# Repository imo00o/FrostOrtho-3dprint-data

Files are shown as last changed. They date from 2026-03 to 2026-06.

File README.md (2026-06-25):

# FrostOrtho-3dprint-data
個人利用の範囲でしたら自由に使用・改変いただけます。  

## バージョン
- v1.2.0  
2026年6月22日以降に頒布しているケース。  
v1.2.0から基板や一部パーツが変更されたためv1.1.0以前と互換性なし。  

- v1.1.0  
2026年5月～6月中旬に頒布しているケース。  
v1.0.0から細かな改善をしたもの。  

- v1.0.0  
キーケット2026以前に頒布した際のケース。  
v1.1.0と互換性があるのでv1.1.0の使用をおすすめします。  

- V0  
試作段階のもの。  
電源スイッチが少し奥にあるため現行のケースとトップケースが少し異なるためv1.0.0以降と互換性がありません。  

## ケース作成
### v1.1.0 ～ v1.2.0
ケースを印刷/発注しただけでは使用できず、別途スポンジやマグネット等の取り付けが必要になります。

#### 必要なもの
| 部品名 | 説明 | 参考購入先 |
| -- | -- | -- |
| スポンジシート(3mm) | ボトムケースに敷くスポンジシート。ポロンスポンジがへたりにくくておすすめです。 | https://www.amazon.co.jp/dp/B00G468722?ref=ppx_yo2ov_dt_b_fed_asin_title&th=1 |
| スポンジシート(2mm) | トップケースに貼るスポンジシート。使いやすくてテープ状のものを使用していますが、2mmくらいの厚さであればなんでも。<br> 透明ケースの場合は100均等にある透明の両面テープが見た目綺麗でおすすめです。 | https://www.amazon.co.jp/dp/B0DDJDYVHX?ref_=ppx_hzsearch_conn_dt_b_fed_asin_title_5&th=1 |
| マグネット(直径2mm × 厚さ1mm) | トラックボールケースとトップケースを着脱可能にするための磁石 | https://www.amazon.co.jp/dp/B0FXB1RH63?ref_=ppx_hzsearch_conn_dt_b_fed_asin_title_1&th=1 |
| ベアリング(外形4mm 内径1.5mm 幅2mm) | トラックボールのベアリング | https://www.amazon.co.jp/dp/B0836S5376?ref_=ppx_hzsearch_conn_dt_b_fed_asin_title_6&th=1 |
| ネジ(M1.4 × 4~5mm) | ベアリングを固定するねじ | https://www.amazon.co.jp/dp/B076ZCH1NJ?ref_=ppx_hzsearch_conn_dt_b_fed_asin_title_1 |

#### 取り付け方
- ボトムケース  
  3mmのスポンジシートを7.5mmくらいの幅にカットします。  
  片面に両面テープを貼ってから切ると貼り付けるのが楽です。  
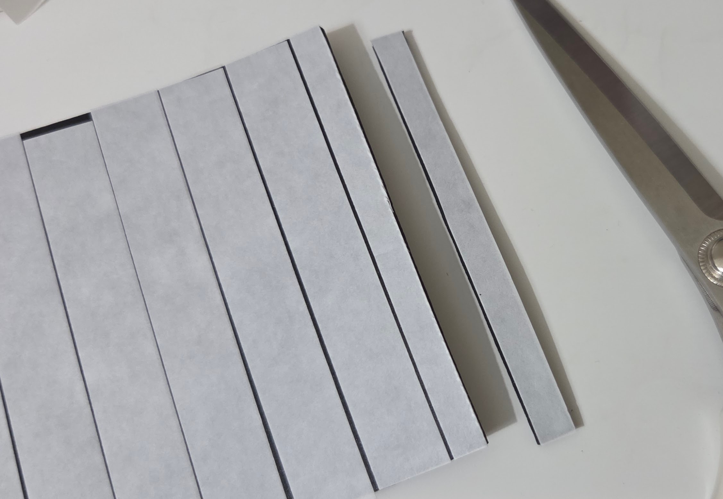
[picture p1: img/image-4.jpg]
   
凹みのある部分にスポンジシートを貼り付けます。  
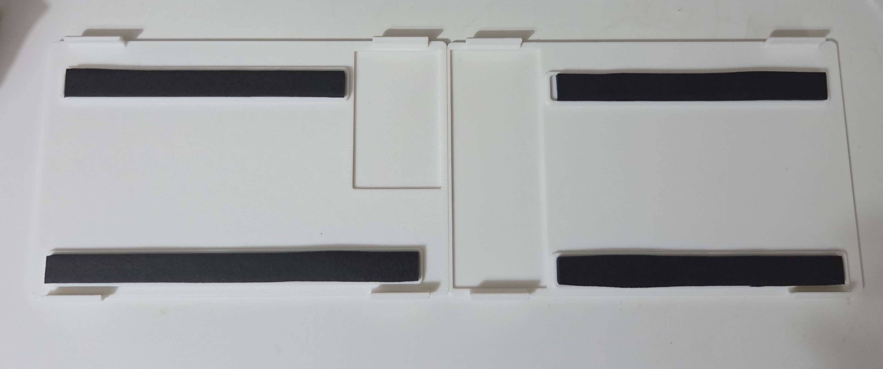
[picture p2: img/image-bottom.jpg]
   
- トップケース  
  2mmのスポンジシートを小さくカットして画像の位置に貼ってください。  
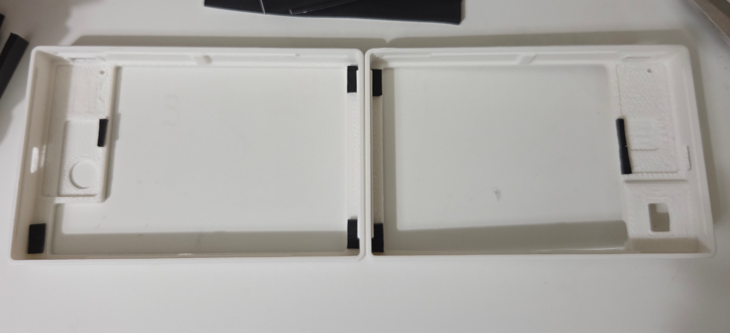
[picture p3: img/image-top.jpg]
     

## 発注方法（JLC3DP）
[JLC3DP](https://jlc3dp.com/jp?spm=Jlc3dp.Homepage.1001)での発注方法について簡単に紹介します。UIは更新される可能性があります。

1. アカウント登録を済ませて発注画面へ
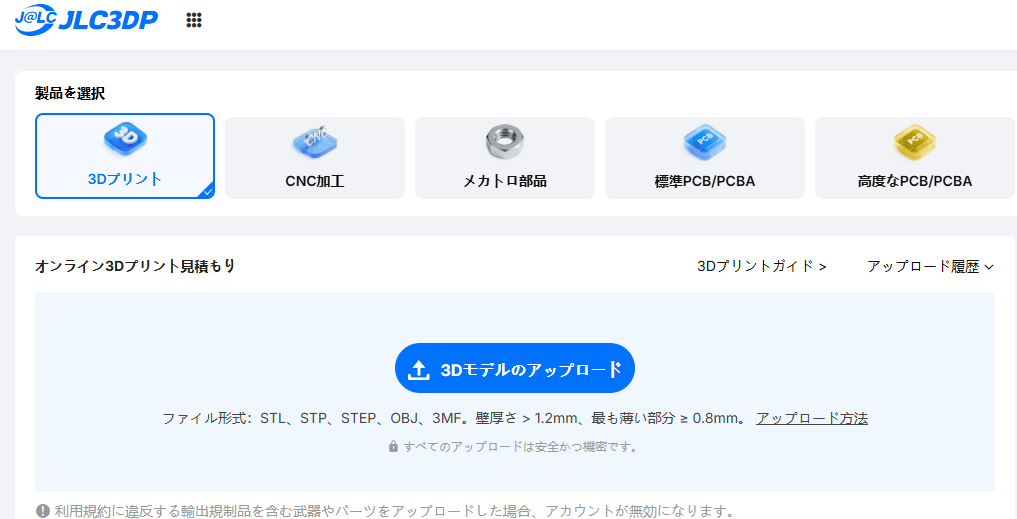
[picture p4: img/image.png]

2. STLファイルをアップロード
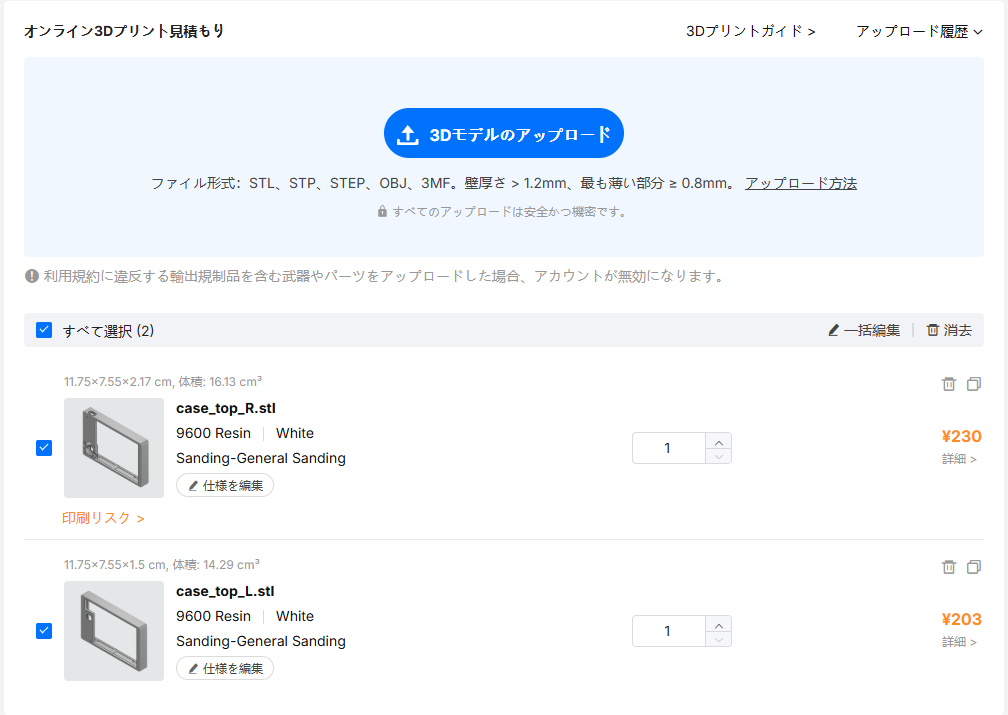
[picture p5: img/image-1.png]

3. 「使用を編集」をクリック
4. 好きな素材を選びます。以下ご参考ください。
   - クリア：SLA(Resin) > 8001レジン > 透明 > オイルスプレー仕上げ  
    表面を削った後にオイルスプレーするので品質にばらつきがあるものの、そのまま組み立てれて綺麗です。  
    ※ 素材の特性上歪んだ状態で届くことがあります。70~80度くらいのお湯で柔らかくして歪みを取ってください。
   - 半透明：SLA(Resin) > 8001レジン > 半透明 > 表面仕上げなし  
    結構バリがあるので自分でやすりがけ必須です。  
    やすりがけやコーティングが苦でなければ、こっちを綺麗に磨いてクリアケースにするのもいいかも。  
    ※ 素材の特性上歪んだ状態で届くことがあります。70~80度くらいのお湯で柔らかくして歪みを取ってください。
   - 黒：MJF(Nylon) > PA12S-HP Nylon > 黒色(染色)  
    PA12S-HPは質感がめちゃくちゃいいです。PA12-HPの方はざらつきが強いので注意。  
   - 例：
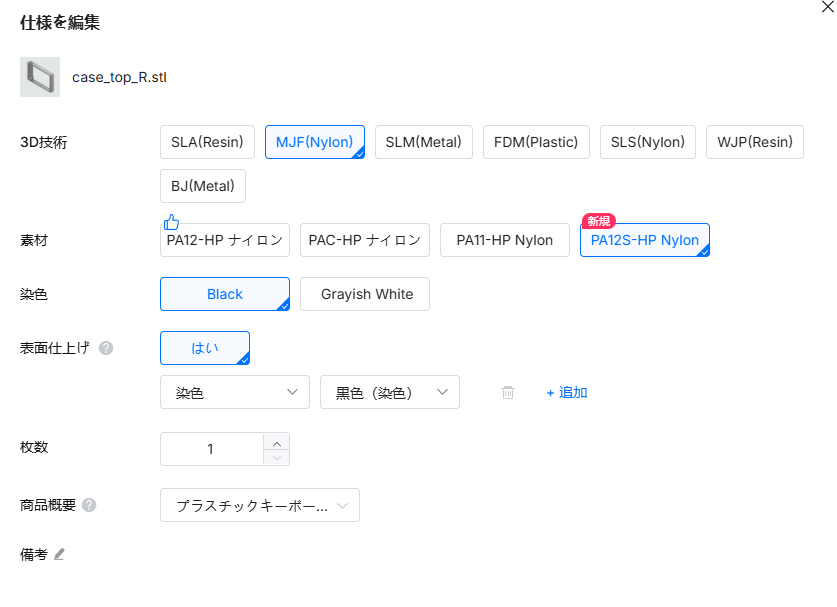
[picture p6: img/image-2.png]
    
5. 印刷リスクが表示された場合は、内容を確認してチェックをつけてください。
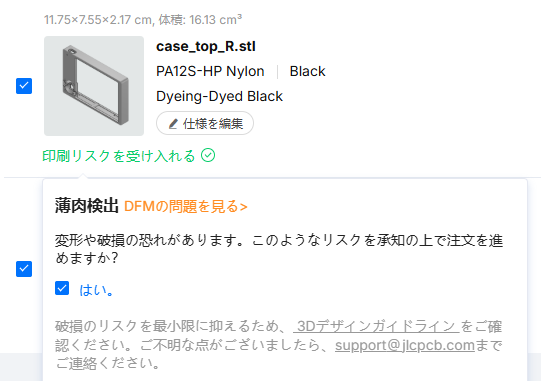
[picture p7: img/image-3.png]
   
6. すべてのパーツで素材を選択したら、「発注する」ボタンをクリック
7. 住所など必要な情報を入力して発注します。レビュー後の支払いになるので、この時点ではまだ支払いはしません。
8. レビュー結果がメールに届きます。  
9. トラボケースで指摘来ることが多いのですが、リスク許容するのでお願いします～て感じで返信してます。
10. すべてのレビューが完了し、Approvedとなったメールが届きます。
11. 発注履歴から支払いをすれば製作開始されます。
12. 製作途中で確認メールが届くことがあるので、届いたら都度対応します。
13. 「Your JLCPCB Order Is On Its Way To You」のメールが届いたらあとは届くのを待つだけです！

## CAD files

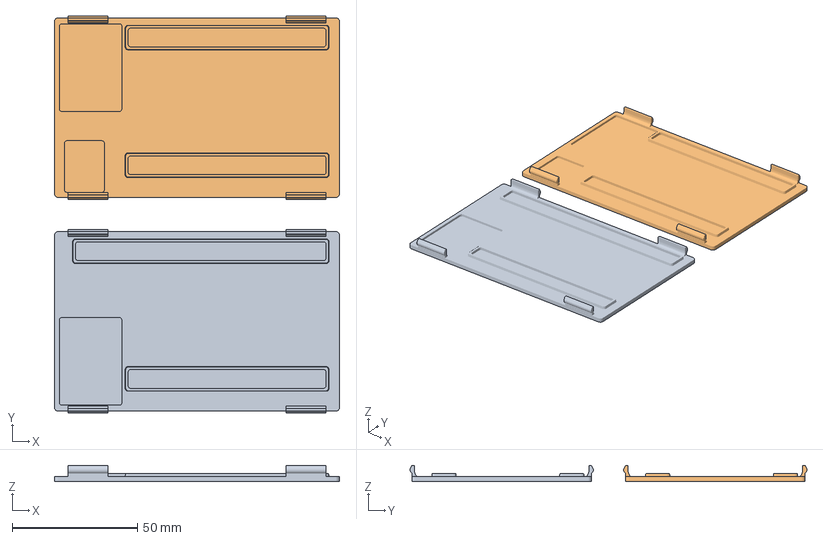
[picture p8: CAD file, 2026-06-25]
case/v1.2.0/3mf/case_bottom.3mf
113.8 x 158.5 x 6.47 mm
case_bottom_L.stl
case_bottom_R.stl

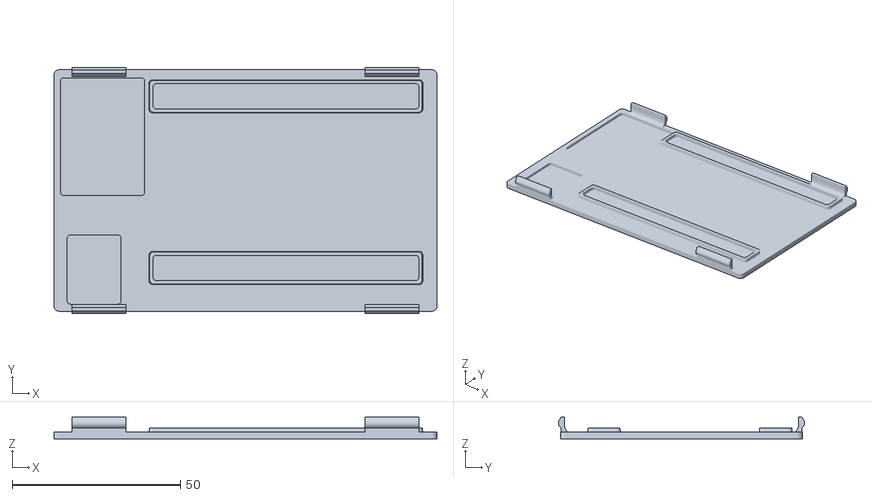
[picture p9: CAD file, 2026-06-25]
case/v1.2.0/stl/case_bottom_R.stl
113.8 x 73.2 x 6.47

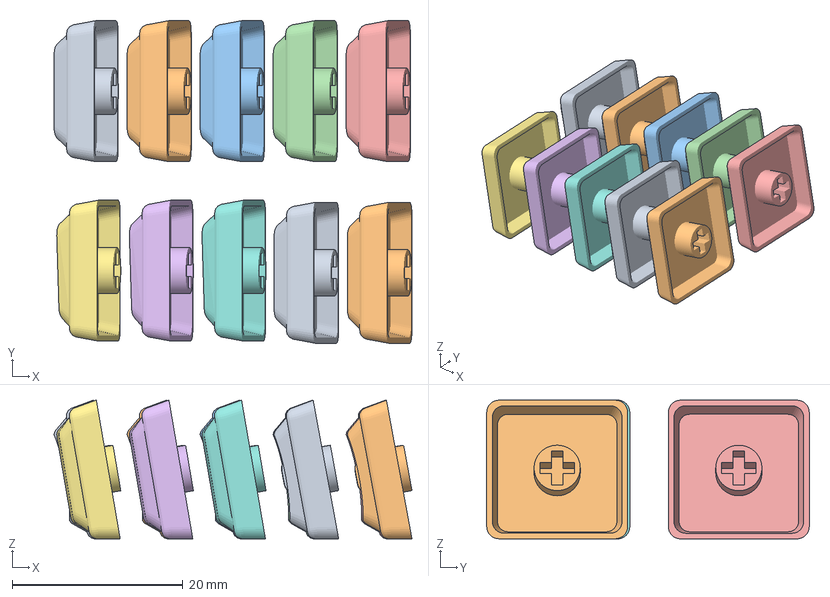
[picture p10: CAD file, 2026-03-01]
keycap/3mf/keycaps.3mf
41.9 x 37.8 x 16.3 mm
keycap-nomal.stl x 5
keycap-flat.stl x 3
keycap-point.stl x 2

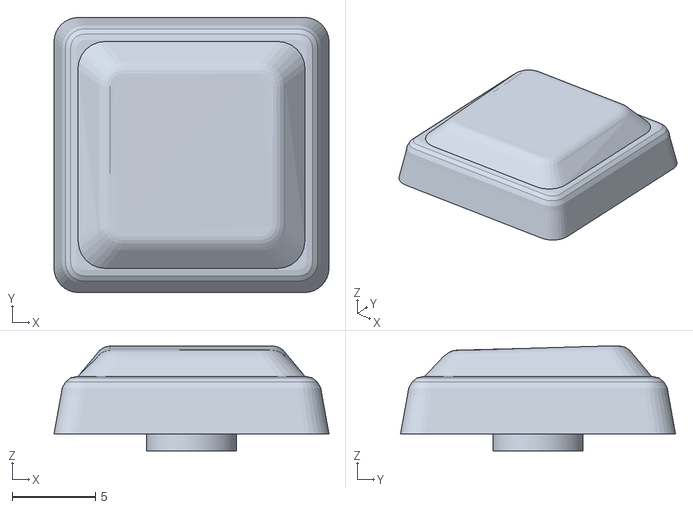
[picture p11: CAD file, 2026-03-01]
keycap/stl/keycap-flat.stl
16.5 x 16.5 x 6.30

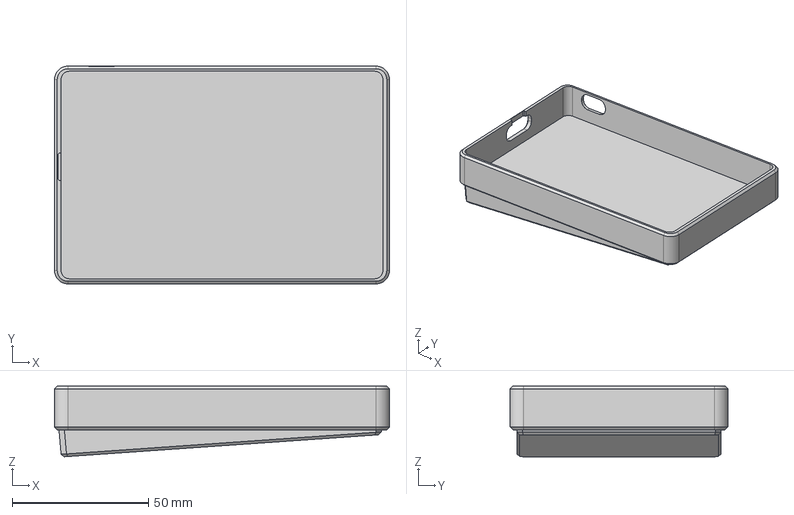
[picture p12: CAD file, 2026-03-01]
V0/case/stl/alumi-case-R.step
123.0 x 80.0 x 25.9 mm

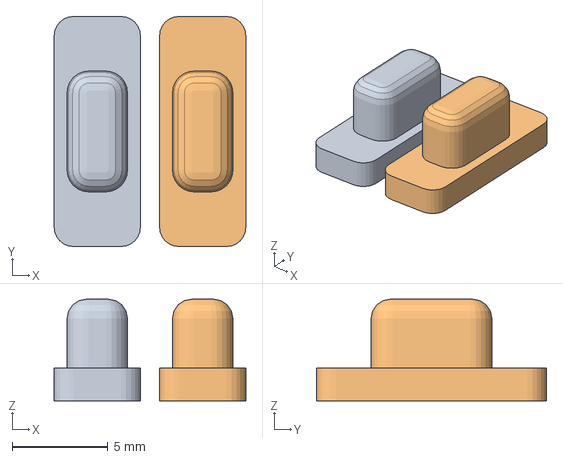
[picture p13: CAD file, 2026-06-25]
case/v1.2.0/3mf/power_slide.3mf
10.0 x 12.0 x 5.30 mm
power_slide.stl x 2

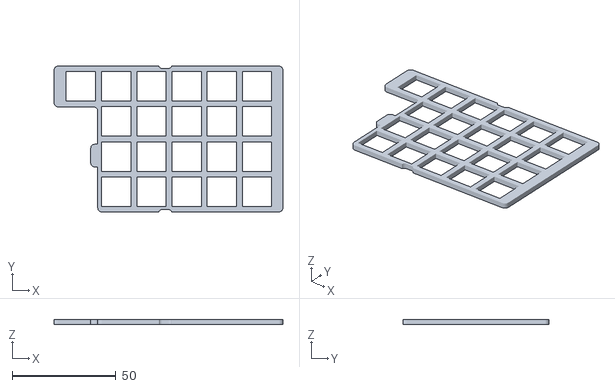
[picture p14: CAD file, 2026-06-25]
case/v1.2.0/stl/switch_plate_L.stl
110.5 x 70.4 x 2.50

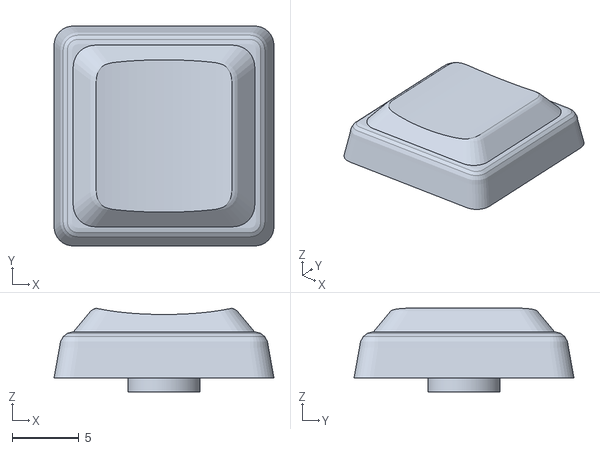
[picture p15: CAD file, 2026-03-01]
keycap/stl/keycap-nomal.stl
16.5 x 16.5 x 6.27

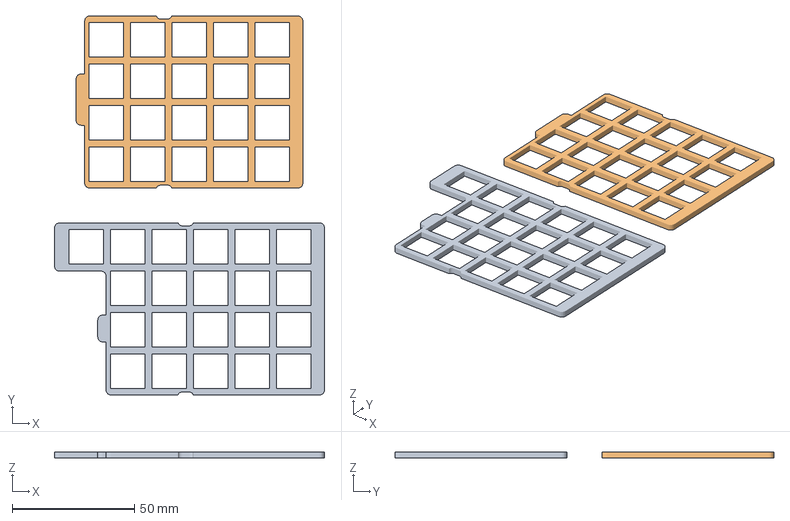
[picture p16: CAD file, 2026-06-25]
case/v1.2.0/3mf/switch_plate.3mf
110.5 x 155.1 x 2.50 mm
switch_plate_L.stl
switch_plate_R.stl

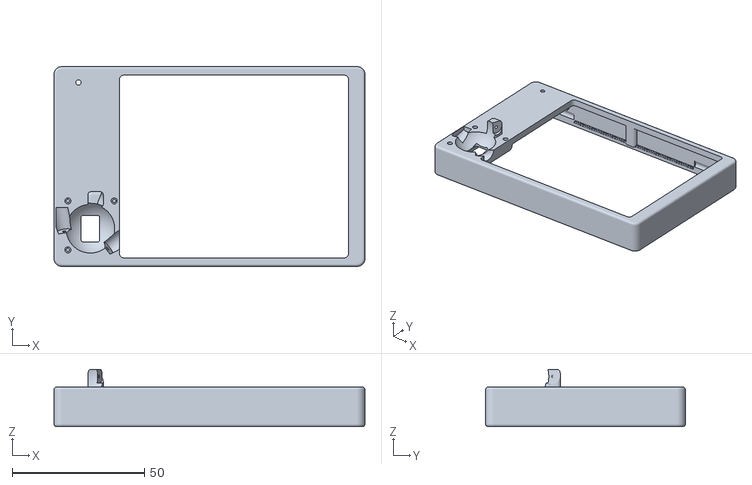
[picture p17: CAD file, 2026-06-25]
case/v1.2.0/stl/case_top_R.stl
117.5 x 75.5 x 21.7

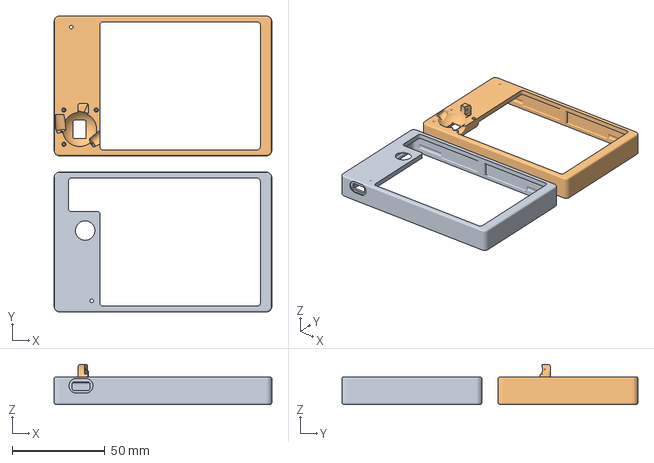
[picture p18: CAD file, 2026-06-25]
case/v1.2.0/3mf/case_top.3mf
117.5 x 159.8 x 21.7 mm
case_top_L.stl
case_top_R.stl

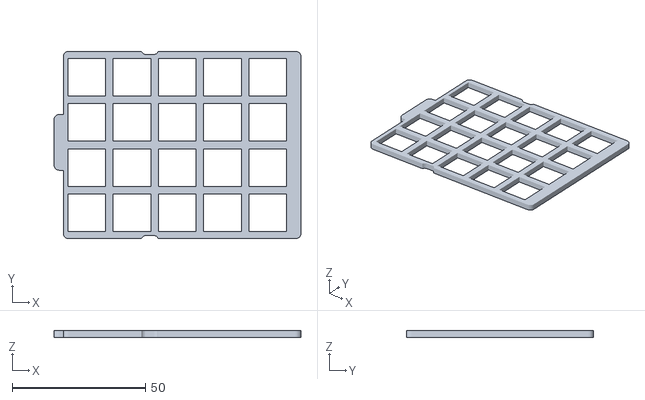
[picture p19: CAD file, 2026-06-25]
case/v1.2.0/stl/switch_plate_R.stl
92.8 x 70.4 x 2.50

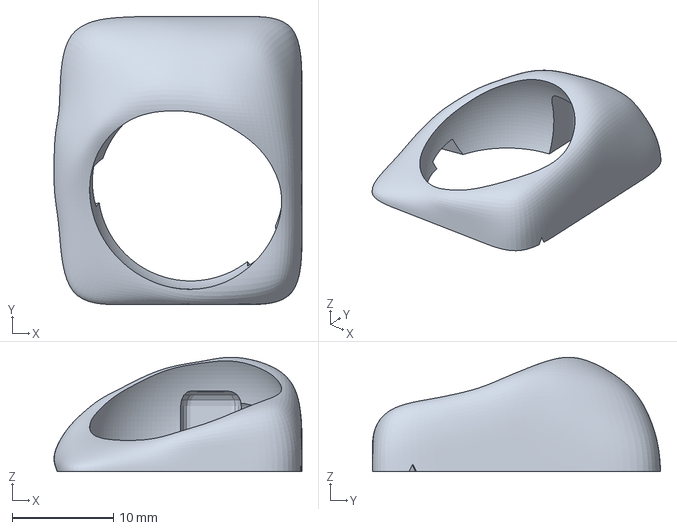
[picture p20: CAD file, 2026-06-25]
case/v1.2.0/3mf/trabo_case.3mf
24.5 x 28.5 x 11.3 mm

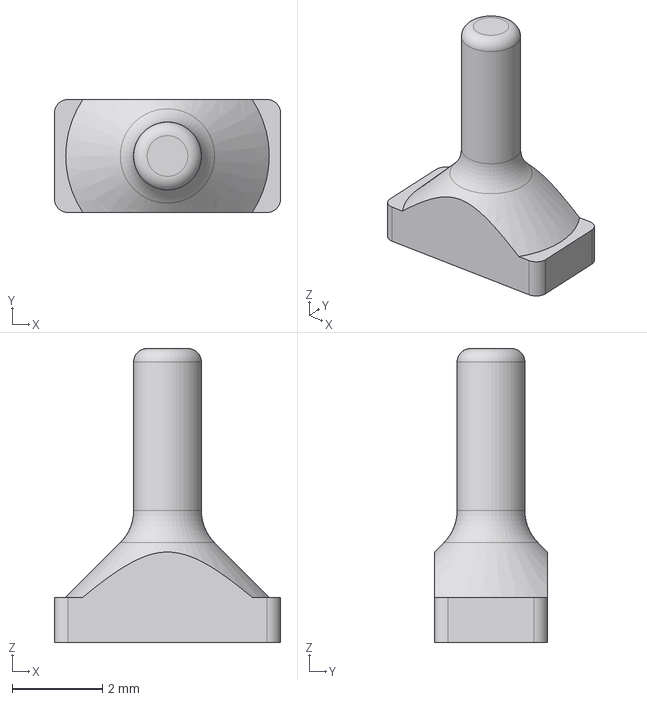
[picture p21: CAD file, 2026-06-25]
case/v1.2.0/stl/reset_stick.step
5.00 x 2.50 x 6.50 mm

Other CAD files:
V0/case/stl/alumi-case-L.step
keycap/stl/keycap-point.stl
case/v1.2.0/3mf/paw3222.3mf
case/v1.2.0/stl/case_top_L.stl
V0/case/3mf/case_top_L.3mf
V0/case/3mf/case_top_R.3mf
case/V0/3mf/case_bottom.3mf
case/V0/3mf/case_top.3mf
case/V0/3mf/nob.3mf
case/V0/3mf/paw3222.3mf
case/V0/3mf/power_slide.3mf
case/V0/3mf/reset_stick.3mf
case/V0/3mf/switch_plate.3mf
case/V0/3mf/trabo_case.3mf
case/V0/old/3mf/case_top_L.3mf
case/V0/old/3mf/case_top_R.3mf
case/V0/old/stl/alumi-case-L.step
case/V0/old/stl/case_top_L.stl
case/V0/old/stl/case_top_R.stl
case/V0/stl/case_bottom_L.stl
case/V0/stl/case_bottom_R.stl
case/V0/stl/case_top_L.stl
case/V0/stl/case_top_R.stl
case/V0/stl/nob.stl
case/V0/stl/paw3222.stl
case/V0/stl/power_slide.stl
case/V0/stl/switch_plate_L.stl
case/V0/stl/switch_plate_R.stl
case/V0/stl/trabo_case.stl
case/V1.0.0/3mf/case_bottom.3mf
case/V1.0.0/3mf/case_top_L.3mf
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

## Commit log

2026-04-24 v1.1追加
    [alumi-case-L.step, alumi-case-R.step, case_bottom.3mf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]
2026-05-10 ドキュメント整備
    [case_bottom.3mf, case_bottom_L.stl, case_bottom_R.stl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]
2026-06-25 add v1.2.0
    [alumi-case-L.step, alumi-case-R.step, case_bottom.3mf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]
2026-07-18 keycap発注用データ追加
2026-07-27 ケース組み立て手順追加
2026-07-30 bottom修正
2026-07-31 注意文追加
2026-08-01 ガイド修正
2026-08-01 ケース微調整
2026-08-05 アルミケース公開
2026-10-25 組み立て手順、ベアリング購入先リンク変更
2026-11-05 v1.3.0追加、折れにくいリセットスティックへ変更
2026-11-05 ドキュメント更新
2026-11-06 ファイル更新
2026-11-08 トラボケース調整
2026-11-12 センサー位置調整
